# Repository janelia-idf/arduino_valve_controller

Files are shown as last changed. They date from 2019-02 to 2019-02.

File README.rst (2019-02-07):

========================
Arduino Valve Controller
========================

Arduino-based device to control 3 Lee Company 3-way ported
LFAA0503110H solenoid valves.

firmware
========

Contains the Arduino firmware files. See firmware/README.rst

host
====

Contains the code for controlling with a host computer.

python
------

See host/python/README.rst

pcb
===

Contains the pcb Kicad and gerber files.

Author: Peter Polidoro

This program is free software: you can redistribute it and/or modify
it under the terms of the GNU Lesser General Public License as published by
the Free Software Foundation, either version 3 of the License, or
(at your option) any later version.

This program is distributed in the hope that it will be useful,
but WITHOUT ANY WARRANTY; without even the implied warranty of
MERCHANTABILITY or FITNESS FOR A PARTICULAR PURPOSE.  See the
GNU Lesser General Public License for more details.

You should have received a copy of the GNU Lesser General Public License
along with this program.  If not, see <http://www.gnu.org/licenses/>.

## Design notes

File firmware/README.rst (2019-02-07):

Arduino Valve Controller Device Firmware
----------------------------------------

Arduino firmware for the arduino_valve_controller device.

For see the INSTALL.rst for installation instructions.

arduino_valve_controller device firmware may be freely distributed
and modified in accordance with the License.

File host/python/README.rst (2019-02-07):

========================
arduino_valve_controller
========================

arduino_valve_controller is a python package to control the
Arduino relay mfc controller over USB, using the python module, the
command line, or a webpage using a webserver.

Install
-------

See INSTALL.rst

Python Module
-------------

Typical usage often looks like this::

    from arduino_valve_controller import ArduinoValveController, ArduinoValveControllers

    valve_controllers = ArduinoValveControllers()
    device_count = len(valve_controllers)
    if device_count == 0:
        raise RuntimeError('No Arduino relay mfc controllers detected, check connections.')
    valve_count = valve_controllers[0].valve_count
    mfc_count = valve_controllers[0].mfc_count

    o = ArduinoValveControllers[0]
    o.setMfcFlowRate(mfc=1,percent_capacity=75)
    print o.getMfcFlowRateSetting(mfc=1)
    print o.getMfcFlowRateMeasure(mfc=0)
    o.setRelayOn(4)
    o.setAllRelaysOff()

Web Page Controls
-----------------

Open a terminal and run::

    arduino_valve_controller_webserver.py

Open a browser and navigate to::

    http://localhost:5000

Author: Peter Polidoro

This program is free software: you can redistribute it and/or modify
it under the terms of the GNU Lesser General Public License as published by
the Free Software Foundation, either version 3 of the License, or
(at your option) any later version.

This program is distributed in the hope that it will be useful,
but WITHOUT ANY WARRANTY; without even the implied warranty of
MERCHANTABILITY or FITNESS FOR A PARTICULAR PURPOSE.  See the
GNU Lesser General Public License for more details.

You should have received a copy of the GNU Lesser General Public License
along with this program.  If not, see <http://www.gnu.org/licenses/>.

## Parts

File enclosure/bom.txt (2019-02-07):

-*- mode:org -*-

# Bill of Materials
| ! | description                                                                                                    | vendor   | part number | quantity |  cost |
|---+----------------------------------------------------------------------------------------------------------------+----------+-------------+----------+-------|
|   | 18-8 Stainless Steel Socket Head Cap Screw, 4-40 Thread, 1-1/2" Length                                         | mcmaster | 92196A119   |        4 |  0.09 |
|   | 18-8 Stainless Steel Socket Head Cap Screw, 4-40 Thread, 1" Length                                             | mcmaster | 92196A115   |        4 |  0.06 |
|   | 18-8 Stainless Steel Socket Head Cap Screw, 2-56 Thread, 3/8" Length                                           | mcmaster | 92196A079   |        4 |  0.06 |
|   | 300 Series Stainless Steel Mil Spec Flat Washer, Number 4 Size, .25" OD, .02"-.03" Thickness, NASM/MS15795-803 | mcmaster | 98019A309   |        4 |  0.01 |
|   | Nylon 6/6 General Purpose Flat Washer, Number 4 Screw Size, .21" OD, .04"-.06" Thick                           | mcmaster | 90295A340   |        4 |  0.05 |
|   | Nylon 6/6 General Purpose Flat Washer, Number 2 Screw Size, .19" OD, .01"-.03" Thick                           | mcmaster | 90295A320   |        4 |  0.06 |
|   | Nylon Unthreaded Spacer, 3/16" OD, 3/16" Length, #4 Screw Size                                                 | mcmaster | 94639A615   |        4 |  0.07 |
|   | Nylon Unthreaded Spacer, 3/16" OD, 1/8" Length, #2 Screw Size                                                  | mcmaster | 94639A610   |        4 |  0.07 |
|   | 18-8 Stainless Steel Broach Style Captive Nut, 4-40 Thread Size, .060" Minimum Panel Thickness                 | mcmaster | 94648A320   |        8 |  0.40 |
|   | 18-8 Stainless Steel Broach Style Captive Nut, 2-56 Thread Size, .060" Minimum Panel Thickness                 | mcmaster | 94648A310   |        4 |  0.41 |
|   | Optically Clear Cast Acrylic Sheet, 1/8" Thick, 12" x 12"                                                      | mcmaster | 8560K239    |        1 |  8.63 |
|   | Optically Clear Cast Acrylic Sheet, 1/4" Thick, 12" x 12"                                                      | mcmaster | 8560K354    |        1 | 16.36 |
|---+----------------------------------------------------------------------------------------------------------------+----------+-------------+----------+-------|
| # | total                                                                                                          |          |             |          | 31.71 |
#+TBLFM: @14$6=(@I$quantity..@II$quantity)*(@I$cost..@II$cost);%.2f;N

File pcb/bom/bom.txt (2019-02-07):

-*- mode:org -*-

# Opt101.lst
| ref     | value                    |
|---------+--------------------------|
| C1      | 10uF                     |
| C2      | 0.1uF                    |
| C3      | 0.1uF                    |
| D1      | LED                      |
| D2      | LED                      |
| D3      | LED                      |
| D4      | LED                      |
| D5      | LED                      |
| D6      | LED                      |
| D7      | LED                      |
| D8      | LED                      |
| D9      | LED                      |
| D10     | LED                      |
| D11     | LED                      |
| D12     | LED                      |
| D13     | LED                      |
| MH1     | CONN_1                   |
| MH2     | CONN_1                   |
| MH3     | CONN_1                   |
| MH4     | CONN_1                   |
| P1      | +5VDC                    |
| R1      | 150                      |
| RP1     | 150                      |
| RP2     | 150                      |
| RP3     | 150                      |
| SHIELD1 | ARDUINO_MEGA_SHIELD_FULL |
| U1      | TLE723X                  |
| U2      | TLE723X                  |
| V1      | VALVE0                   |
| V2      | VALVE1                   |
| V3      | VALVE2                   |
| V4      | VALVE3                   |
| V5      | VALVE4                   |
| V6      | VALVE5                   |
| V7      | VALVE6                   |
| V8      | VALVE7                   |
| V9      | VALVE8                   |
| V10     | VALVE9                   |
| V11     | VALVE10                  |
| V12     | VALVE11                  |

# Bill of Materials
| ! | part    | description                                  | vendor      | part number     | quantity |   cost |
|---+---------+----------------------------------------------+-------------+-----------------+----------+--------|
|   | PCB     | arduino_valve_control                        | pcbuniverse | v1.1            |        1 |   1.00 |
|   | C1      | CAP CER 10UF 50V 10% X7S 1210                | digikey     | 445-4536-1-ND   |        1 |   1.24 |
|   | C2-3    | CAP CER 0.1UF 50V 10% X7R 1210               | digikey     | 478-3586-1-ND   |        2 |   0.39 |
|   | D1-13   | LED GREEN CLEAR 0805 SMD                     | digikey     | 160-1179-1-ND   |       13 |   0.35 |
|   | P1      | CONN PWR JACK DC 2.1X5.5 8A T/H              | digikey     | CP-063AH-ND     |        1 |   1.78 |
|   | P1      | TRANSFORMER DESK TOP 5V 18W                  | digikey     | T1193-P5P-ND    |        1 |  16.37 |
|   | R1      | RES 150 OHM 1/4W 5% 1210 SMD                 | digikey     | RHM150BECT-ND   |        1 |   0.15 |
|   | RP1-3   | RES ARRAY 150 OHM 4 RES 2012                 | digikey     | CRA12E8150CT-ND |        3 |   0.23 |
|   | SHIELD1 | BOARD MCU MEGA2560                           | digikey     | 1050-1018-ND    |        1 |  51.91 |
|   | SHIELD1 | CONN HDR VERT 50POS .100" SNGL               | digikey     | SAM1055-50-ND   |        2 |   3.42 |
|   | U1      | IC SW SMART OCTAL LOWSIDE PDSO24             | digikey     | TLE7230GCT-ND   |        2 |   4.62 |
|   | V1-12   | CONN RECEPT PIN .032-.046" .240"             | digikey     | ED1013-ND       |       24 |   0.92 |
|   | V1-12   | 3-Way Ported Style with Circuit Board Mounts | theleeco    | LFAA0503110H    |       12 |   1.00 |
|---+---------+----------------------------------------------+-------------+-----------------+----------+--------|
| # | total   |                                              |             |                 |          | 128.63 |
#+TBLFM: @15$7=(@I$quantity..@II$quantity)*(@I$cost..@II$cost);%.2f;N

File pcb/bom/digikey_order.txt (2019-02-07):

20, 445-4536-1-ND
20, 478-3586-1-ND
100, 160-1179-1-ND
10, CP-063AH-ND
10, T1193-P5P-ND
20, RHM150BECT-ND
40, CRA12E8150CT-ND
6, 1050-1018-ND
20, SAM1055-50-ND
20, TLE7230GCT-ND
200, ED1013-ND

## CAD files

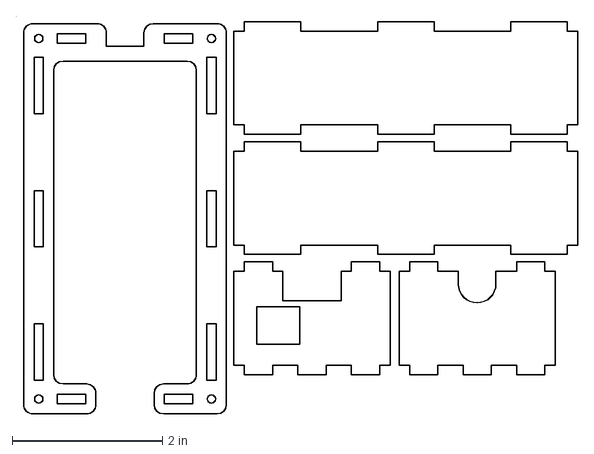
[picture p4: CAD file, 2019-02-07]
enclosure/arduino_valve_controller_enclosure.125in.dxf
7.48 x 5.30 in

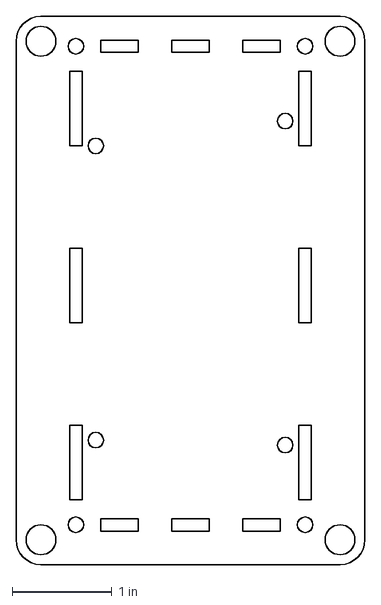
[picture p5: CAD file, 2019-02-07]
enclosure/arduino_valve_controller_enclosure.25in.dxf
3.50 x 5.50 in

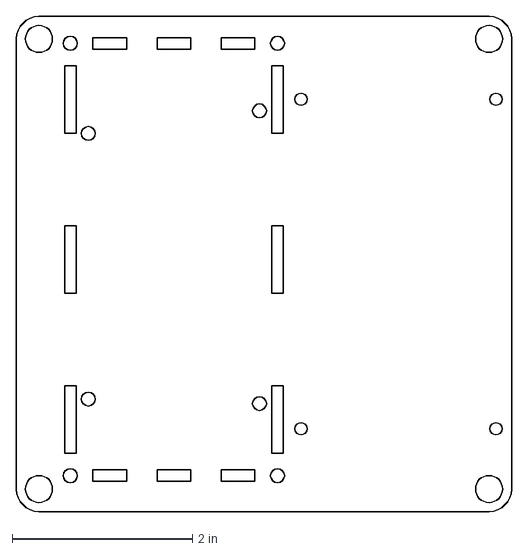
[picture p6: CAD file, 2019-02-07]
enclosure/arduino_valve_controller_enclosure_display.25in.dxf
5.50 x 5.50 in

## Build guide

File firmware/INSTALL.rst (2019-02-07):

Firmware installation instructions
-----------------------------------

Requirements:

The following libraries should be placed in the arduino sketchbook libraries
directory.

* Streaming              https://bitbucket.org/peterpolidoro/arduino_libs/src
* SerialReceiver         https://bitbucket.org/peterpolidoro/arduino_libs/src
* DictPrinter            https://bitbucket.org/peterpolidoro/arduino_libs/src
* Tle7232g               https://bitbucket.org/peterpolidoro/arduino_libs/src
* TimeTriggeredScheduler https://bitbucket.org/peterpolidoro/arduino_libs/src

Build and upload the firmware using the Arduino IDE.

see http://arduino.cc/en/Guide/Environment for instructions on using the IDE.

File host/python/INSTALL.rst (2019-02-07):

arduino_valve_controller installation instructions
------------------------------------------------------

* Create a new virtual environment if necessary::

    virtualenv --system-site-packages ~/virtualenvs/arduino_valve_controller

* Activate a virtual environment::

    source ~/virtualenvs/arduino_valve_controller/bin/activate

* Install dependencies::

    pip install flask --upgrade
    pip install flask-sijax --upgrade

* Clone bitbucket mercurial repositories::

    mkdir ~/mercurial
    cd ~/mercurial
    hg clone https://bitbucket.org/peterpolidoro/python_libs/
    hg clone https://bitbucket.org/peterpolidoro/arduino_valve_controller/

* Install python packages::

    cd ~/mercurial/python_libs/arduino_device
    python cleanup.py
    python setup.py install
    cd ~/mercurial/arduino_valve_controller/host/python
    python cleanup.py
    python setup.py install

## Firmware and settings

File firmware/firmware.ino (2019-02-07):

#include <SPI.h>
#include <Streaming.h>
#include <EEPROM.h>
#include <util/atomic.h>

#include "SerialReceiver.h"
#include "DictPrinter.h"
#include "Tle7232g.h"
#include "Bronkhorst.h"
#include "TimeTriggeredScheduler.h"
#include "NewhavenDisplay.h"
#include "TimerThree.h"

#include "constants.h"
#include "SystemState.h"
#include "MessageHandler.h"

void setup() {
    Serial.begin(constants::baudrate);
    systemState.initialize();
}

void loop() {
    messageHandler.processMsg();
    systemState.updateDisplay();
}

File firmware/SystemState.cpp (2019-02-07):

#if defined(ARDUINO) && ARDUINO >= 100
#include "Arduino.h"
#else
#include "WProgram.h"
#endif
#include "string.h"
#include "SystemState.h"

SystemState::SystemState() {
  setErrMsg("");
}

void SystemState::setErrMsg(char *msg) {
  strncpy(errMsg,msg,SYS_ERR_BUF_SZ);
}

void SystemState::initialize() {
  relayDriver = TLE7232G(constants::relayDriverCsPin,constants::relayDriverInPin);

  for (int mfcIndex=0; mfcIndex<constants::mfcCount; mfcIndex++) {
    mfc[mfcIndex] = Bronkhorst(mfcIndex+1);
    mfc[mfcIndex].init();
  }

  // Initialize SPI:
  SPI.setDataMode(SPI_MODE1);
  SPI.setClockDivider(SPI_CLOCK_DIV4);
  SPI.setBitOrder(MSBFIRST);
  SPI.begin();

  relayDriver.init(1);
  setAllRelaysOff();

  tts.init();

  for (int relay; relay < constants::relayCount; relay++) {
    relayBlinkTasks[relay].onTaskId = -1;
    relayBlinkTasks[relay].offTaskId = -1;
  }

  for (int digital_output; digital_output < constants::digitalOutputCount; digital_output++) {
    pinMode(constants::digitalOutputPins[digital_output], OUTPUT);
    digitalWrite(constants::digitalOutputPins[digital_output], LOW);
    digitalOutputStates[digital_output] = LOW;
  }

  for (int digital_input; digital_input < constants::digitalInputCount; digital_input++) {
    pinMode(constants::digitalInputPins[digital_input], INPUT);
    digitalWrite(constants::digitalInputPins[digital_input], HIGH);
  }

  for (int analog_input; analog_input < constants::analogInputCount; analog_input++) {
    pinMode(constants::analogInputPinAliases[analog_input], INPUT);
    digitalWrite(constants::analogInputPinAliases[analog_input], LOW);
  }

  // Display
  display = NewhavenDisplay();
  initializeDisplay();

  if (constants::mappingEnabledDefault) {
    startAnalogInputsMapping();
  }
}

bool SystemState::setRelays(uint32_t relays) {
  relayDriver.setChannels(relays);
  return true;
}

bool SystemState::setRelayOn(int relay) {
  relayDriver.setChannelOn(relay);
  return true;
}

bool SystemState::setRelayOff(int relay) {
  relayDriver.setChannelOff(relay);
  return true;
}

bool SystemState::setAllRelaysOn() {
  uint32_t relays = 0;
  relays = ~relays;
  setRelays(relays);
  return true;
}

bool SystemState::setAllRelaysOff() {
  uint32_t relays = 0;
  setRelays(relays);
  return true;
}

bool SystemState::setMfcFlowRate(int mfcIndex, int percent_capacity) {
  int setpoint = map(percent_capacity,constants::percentCapacityMin,constants::percentCapacityMax,constants::setpointMin,constants::setpointMax);
  return mfc[mfcIndex].setSetpoint(setpoint);
}

bool SystemState::getMfcFlowRateSetting(int mfcIndex, int &percent_capacity) {
  int setpoint = mfc[mfcIndex].getSetpoint();
  percent_capacity = map(setpoint,constants::setpointMin,constants::setpointMax,constants::percentCapacityMin,constants::percentCapacityMax);
  return true;
}

bool SystemState::getMfcFlowRateMeasure(int mfcIndex, int &percent_capacity) {
  int measure = mfc[mfcIndex].getMeasure();
  percent_capacity = map(measure,constants::setpointMin,constants::setpointMax,constants::percentCapacityMin,constants::percentCapacityMax);
  return true;
}

bool SystemState::getMfcSerialNumber(int mfcIndex, String &serial_number) {
  return mfc[mfcIndex].getSerialNumber(serial_number);
}

bool SystemState::getMfcCapacity(int mfcIndex, int &capacity) {
  capacity = (int)mfc[mfcIndex].getCapacity();
  return true;
}

bool SystemState::getMfcCapacityUnits(int mfcIndex, String &capacity_units) {
  return mfc[mfcIndex].getCapacityUnits(capacity_units);
}

bool SystemState::getMfcFluidName(int mfcIndex, String &fluid_name) {
  return mfc[mfcIndex].getFluidName(fluid_name);
}

bool SystemState::startRelayBlink(int relay, long period, int duty_cycle, long count=-1) {
  stopRelayBlink(relay);
  if ((0 < duty_cycle) && (duty_cycle < 100)) {
    int onTaskId = (int)tts.addTaskUsingDelay(100,inlineSetRelayOn,relay,period,count,false);
    int offTaskId = (int)tts.addTaskUsingOffset((uint8_t)onTaskId,(period*duty_cycle)/100,inlineSetRelayOff,relay,period,count,false);

    // Only save continuous blink patterns. Let patterns with count
    // expire naturally. This means multiple blink patterns could
    // overlap until count expires and that finite blink patterns
    // cannot be stopped unless all tasks are removed.

    if (count < 0) {
      relayBlinkTasks[relay].onTaskId = onTaskId;
      relayBlinkTasks[relay].offTaskId = offTaskId;
    }
  } else if (100 <= duty_cycle) {
    setRelayOn(relay);
  }
  return true;
}

bool SystemState::stopRelayBlink(int relay) {
  int onTaskId = relayBlinkTasks[relay].onTaskId;
  int offTaskId = relayBlinkTasks[relay].offTaskId;
  if (0 <= onTaskId) {
    tts.removeTask((uint8_t)onTaskId);
    relayBlinkTasks[relay].onTaskId = -1;
  }
  if (0 <= offTaskId) {
    tts.removeTask((uint8_t)offTaskId);
    relayBlinkTasks[relay].offTaskId = -1;
  }
  setRelayOff(relay);
  return true;
}

bool SystemState::stopAllRelaysBlink() {
  for (uint8_t relay; relay < constants::relayCount; relay++) {
    stopRelayBlink(relay);
  }
  return true;
}

bool SystemState::addPulseCentered(int relay, long delay, long duration) {
  long rising = delay - duration/2;
  if (rising < 0) {
    rising = 0;
  }
  int onTaskId = (int)tts.addTaskUsingDelay(rising,inlineSetRelayOn,relay,-1,-1,false);
  tts.addTaskUsingOffset((uint8_t)onTaskId,duration,inlineSetRelayOff,relay,-1,-1,false);
  return true;
}

bool SystemState::setDigitalOutputHigh(int digital_output) {
  digitalWrite(constants::digitalOutputPins[digital_output], HIGH);
  digitalOutputStates[digital_output] = HIGH;
  return true;
}

bool SystemState::setDigitalOutputLow(int digital_output) {
  digitalWrite(constants::digitalOutputPins[digital_output], LOW);
  digitalOutputStates[digital_output] = LOW;
  return true;
}

bool SystemState::toggleDigitalOutput(int digital_output) {
  if (digitalOutputStates[digital_output] == LOW) {
    setDigitalOutputHigh(digital_output);
  } else {
    setDigitalOutputLow(digital_output);
  }
  return true;
}

bool SystemState::pulseDigitalOutput(int digital_output, long duration) {
  int onTaskId = (int)tts.addTaskUsingDelay(0,inlineSetDigitalOutputHigh,digital_output,-1,-1,false);
  tts.addTaskUsingOffset((uint8_t)onTaskId,duration,inlineSetDigitalOutputLow,digital_output,-1,-1,false);
  return true;
}

int SystemState::getDigitalInput(int digital_input) {
  return digitalRead(constants::digitalInputPins[digital_input]);
}

int SystemState::getAnalogInput(int analog_input) {
  return analogRead(constants::analogInputPins[analog_input]);
}

bool SystemState::removeAllTasks() {
  return tts.removeAllTasks();
}

uint32_t SystemState::getTime() {
  return tts.ms();
}

bool SystemState::setTime(uint32_t time=0) {
  tts.setTime(time);
  return true;
}

bool SystemState::getTaskDetails(uint8_t taskId, uint32_t& time, int& arg, long& period, long& count, bool& free, bool& enabled) {
  tts.getTaskDetails(taskId, time, arg, period, count, free, enabled);
  return true;
}
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
